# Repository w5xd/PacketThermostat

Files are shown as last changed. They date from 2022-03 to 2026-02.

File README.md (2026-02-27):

<h2>Packet Thermostat Project</h2>

<p>Do you want to access your HVAC over the internet, but not want to open up your home network
some manufacturer's offshore web portal?
Here is an add-on that works on most HVAC systems (<i>i.e.</i> those with 24VAC control 
signals.) You keep
your existing thermostat whether or not it has wifi capability. This packet thermostat exchanges 
radio packets with a gateway to
your Windows or Linux PC. The PC can, in the simplest mode, just monitor the wired
thermostat and report its commands. Or it can modify the commands to, for example, convert a call for
heat pump to a call for the furnace, or it can ignore the wired thermostat and take over 
full control. </p>

It has no hardware buttons. Adjust your conventional thermostat for your comfort when you 
are at home, while instructing this thermostat to its pass-through mode.

The Packet Thermostat must be installed along the wires
between the HVAC and the conventional thermostat. It doesn't matter where as long as there is a way to provide 5VDC to it. 
The packet radio has a range of roughly 500m from the Packet Gateway on a PC.

When you are not at home and need your HVAC settings to change, send a radio packet from the gateway to set this Packet 
Thermostat to one of its controlling modes. 
If your system has one of the simpler one stage or two stage conventional thermostats, the sketch and application
 presented here likely duplicate
its functionality without customization. 

If your HVAC instead has control requirements beyond that implemented here, this project is open source and
free for you to modify. Any HVAC system
with 24V AC control signals and with up to six controls from the thermostat and up to seven 
signals at the furnace can be implemented. (Of what use is that seventh output beyond the six inputs? Maybe 
your HVAC system
has an auxilliary duct booster fan that needs to be activated, say, whenever any of the other six is on.)

This design facilitates integrating the application into a web based home automation system.

There is no GUI for this thermostat in this repository. The repository at 
<a href='http://github.com/w5xd/diysha'>http://github.com/w5xd/diysha</a>
implements a web server that can be used to remotely control this device over the internet.

The device design consists of:
<ul>
<li>A printed circuit board (PCB) which hosts an Arduino, an RFM69 packet radio, 8 total wires (which must include
a power and a common) toward 
the standard wired thermostat, and 14 wires
toward the HVAC. The surplus of wires toward the HVAC unit are to support wired thermometers so this unit
can monitor what is happening right at the furnace. All the parts on the PCB are available at this writing as documented
by this
<a href='https://www.mouser.com/Tools/Project/Share?AccessID=1a8a35c924'>Mouser shared project.</a>.
<li>An enclosure of 3D printable parts that mounts the PCB along with 3 molex connectors. 
This repository has the printable STL files, and also the Solidworks model used to
generate them.
<li>An Arduino sketch.
<li>A command line application  that runs on either Linux or Windows for the purpose of setting
the detailed configuration of the thermostat EEPROM customized to the actual wiring in your HVAC system.
<li><a href='Assembly.md'>Construction details are here</a>.</li>
</ul>

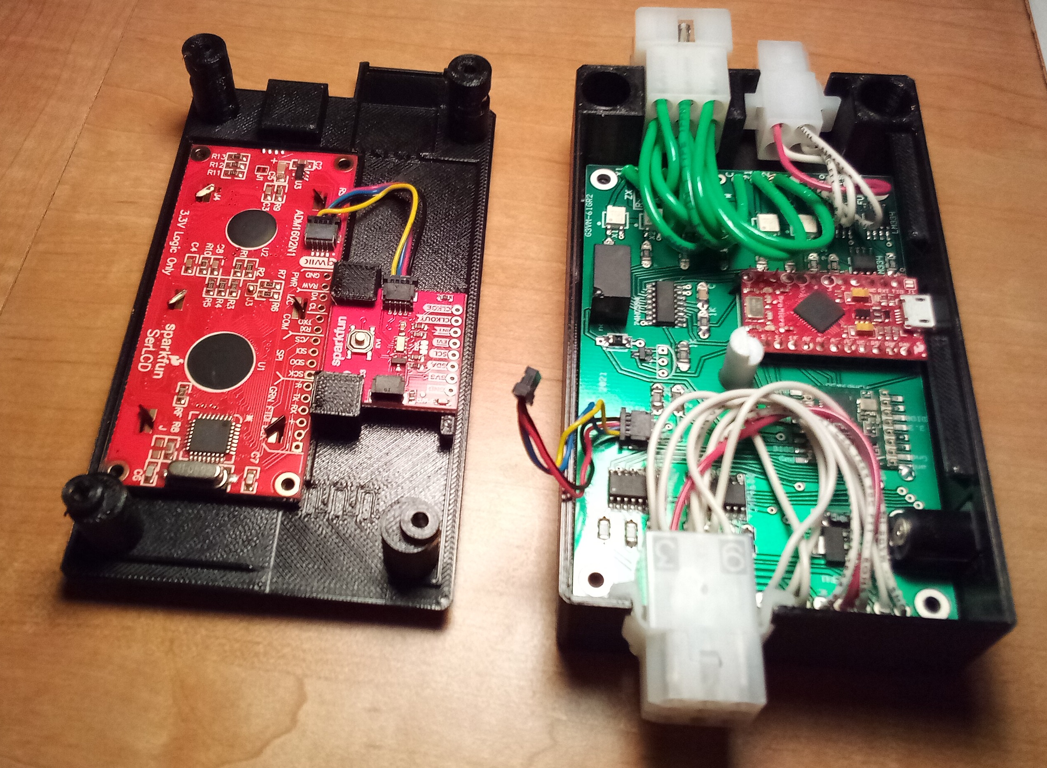
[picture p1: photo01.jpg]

<p style='font-size:11px;font-style:italic'>The PCB version in the photo is older. The CPU in the latest revision
 is a Teensy, and the qwiic connector has opposite orientation, but otherwise the older and new boards are
very similar.</p>

A good summary of the standard
names, colors, and functions of thermostat control wires can be found
<a href='https://www.epatest.com/store/resources/images/misc/how-a-thermostat-operates.pdf'>here</a>.
In terms of that traditional thermostat wiring nomenclature, this PCB supports any installation using 
up to two 24VAC power sources:
<ul>
<li> C (24VAC common)
<li> Either a single R wire, or separate R heat from R cool. (24VAC source or sources traditionally called Rc and Rh.)
</ul>
Signal wires:
<ul>
<li> W, W1 and/or W2 (3 stages of heat)
<li> Y, Y1 and/or Y2 (3 stages of cooling)
<li> O or B (heat pump reversing valve control)
<li> Dehum (dehumidify)
<li> ...any other 24VAC signal that your installation might need up to a total of 6 inputs from the thermostat, and 7 outputs to the HVAC.
</ul>

Of the standard wire names only C, R and W appear on the PCB silkscreen and in the sketch.
For the remaining signals, the convention
in this design is to use the letters X and Z to name them. It is up to the PacketThermostatSettings application to
assign the standard names that appear in your particular HVAC installation to the generic names on this 
thermostat's PCB and sketch.

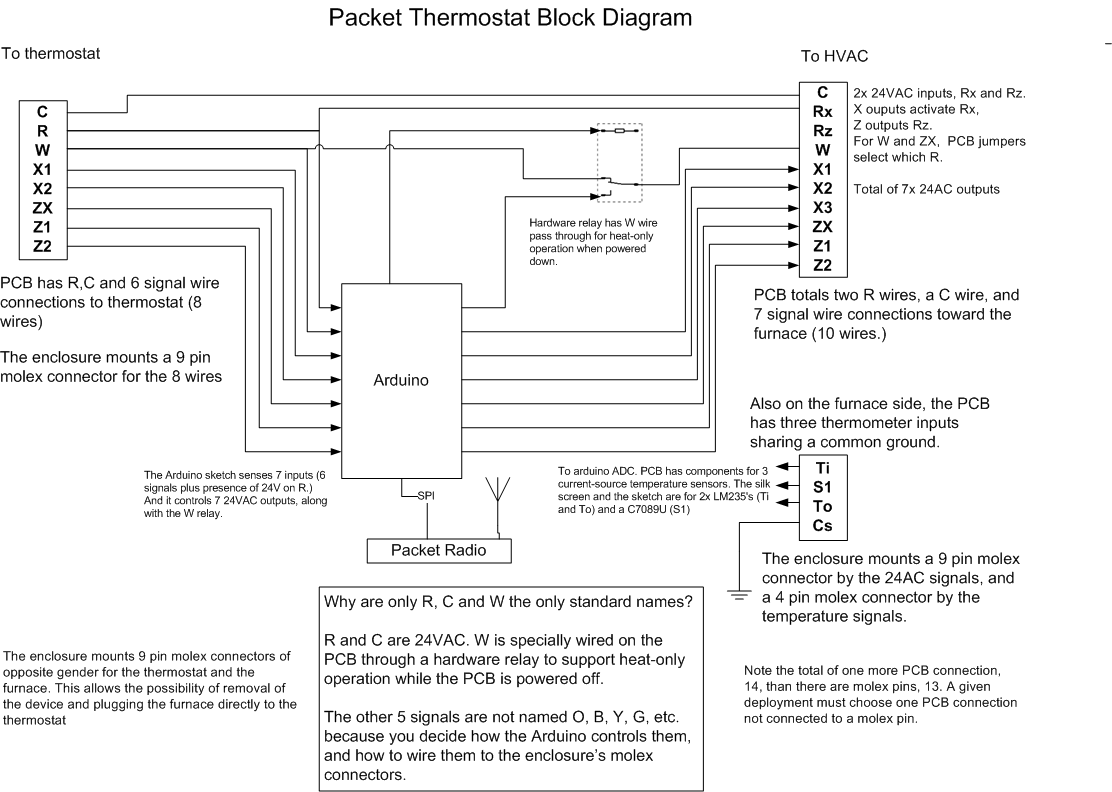
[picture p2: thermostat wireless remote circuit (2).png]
thermostat wireless remote circuit (2).png


The block diagram above shows that the W wire is treated uniquely. It is routed through a hardware relay
that passes the heat signal (W) through when the PCB is powered down. This allows a fail-safe operation so the 
heating function still works
if the Packet Thermostat is not powered, and is why the W wire keeps its standard name. However, 
the PacketThermostatSettings 
application could be modified to reassign even the W wire if your application requires some signal other than W
to be passed through while the 5VDC power is unavailable.

The standard name is also used for the 24VAC supply, R. Like the standard in conventional thermostats,
as many as two are supported by the PCB. But it doesn't use the standard names Rc and Rh. Their names in this 
design are Rx and Rz in order to indicate that the PCB's output signals named
X1 through X3 are powered by Rx, while Z1 and Z2 are powered by Rz. The remaining two outputs, W and ZX are wired
to PCB jumpers to enable installation-specific 24V power from either Rx or Rz on those signals.
If your furnace has only one R wire, the PCB provides a position to jumper the Rx and Rz terminals to each other.

The furnace-facing side of PCB has 4 terminals to support 3 wired thermometer inputs sharing a 
common ground. The sketch
includes the necessary programming to convert the Arduino ADC pin reading for either an 
LM235 solid state thermometer or 
a Honeywell C7089U thermistor.
The silk screen and sketch call out two LM235's and one thermistor, but the only difference 
between the two devices
is one resistor value along with the corresponding programming in the sketch. 
Any combination of those two sensor types totalling 3 can be supported by
substituting the appriorate resistor and modifying the sketch. 

In addition to sending and receiving packets with the Packet Gateway for status updates and changes, the sketch
puts its RFM69 in spy mode such that it receives any Packet Thermometer notifications on its same radio 
frequency and network ID.
Such a Packet Thermometer temperature update (along with its relative humdity update if it sports an HIH6130) are
available to the Packet Thermostat sketch.

The provided sketch software supports being set into any of the following operating types:
<ol>
<li> Pass through.<br/>In this type, it copies each of its 6 inputs to its corresponding output. W to W, X1 to X1, 
X2 to X2, ZX to ZX, Z1 to Z1, and Z2 to Z2. Because it has no corresponding input, X3 will never 
be asserted in Pass through mode.
<li> Map input to output. <br/>In this mode, the thermostat takes its 6 inputs 
(which correspond to 2**6 = 64 combinations)
and updates its 7 outputs to the corresponding value in a 64 byte table. The table is 
configured by the PacketThermostatSettings
application and loaded into the Arduino EEPROM.
<li> Heat. <br/>The thermostat ignores its thermostat inputs. It is instead driven by notifications from one or more 
Packet Thermometers.
This type has several radio-controled settings. One for its target temperature (the turn OFF setting), 
another for its active temperature (its turn ON setting)
along with the required output wire signals for Stage 1, Stage 2, and Stage 3 heating. This thermostat commands Stage 1
on first encountering the activate temperature, then moves to Stage 2 and Stage 3 if the continuous ON time exceeds
the corresponding settings. 
<li> Cool. <br/>The behavior in this type takes the same settings as heat, but takes the opposite 
conditions on the received temperature.
It starts Stage 1 when a temperature
notification exceeds the activate setting, and stops when a notification is below the target. The Cool mode 
also adds a dehumidify setting and a dehumidify output mask. When the humidity is above the setting, the Cool
mode modifies its output.
<li> Auto.<br/>The auto type supports all the Cool type settings and adds a heat target temperature, 
a heat activate temperature, and Stage 1, 2 and 3 timings and output control wire settings.
</ol>

All the above settings are settable by radio packets or by a wired serial port, and all can be commanded to
be stored in the Arduino's EEPROM. The commands are documented in <a href='./Commands.md'>Commands.md</a>. 
Each type also has a five character name, which it will display on the LCD when
commanded into that mode.

The sketch supports a scheduling feature to adjust the Packet Thermostat's target temperature when 
its real time clock reaches a given
hour and minute and day-of-week. It supports a maximum of 16 time points, each with its own target temperature.

The sketch supports a safety shutdown feature that can be configured via its radio or serial port. 
It is independent of the mode settings listed above.
The feature has a trigger temperature for the HVAC input temperature sensor. 
<i>When this trigger temperature is exceeded while the thermostat is in a heating mode, the furnace 
is shut down for a timed interval.</i>
The PacketThermostatSettings application is an easy way to set up
this feature. It sets the required parameters that configure this feature: the trigger 
temperature, the shutdown time,
the thermostat signal combinations that indicate a heat mode, and the thermostat signals to 
turn off to shut down the furnace.

<h2>Power</h2>
The device requires its own 5V power supply. For programming the Arduino, the Teensy version (PCB version 3 and later)
requires both the micro USB connection and the 5V DC power applied. The older PCB with the Pro Micro require
programming using an ISP programmer and with 5V DC not applied.

<h2>Sketch</h2>

PCB version 3 and later has the Teensy 4.0 Arduino, which has far more than enough EEPROM and memory for the sketch.
Earlier versions of the PCB have the Pro Micro. The Pro Micro's flash memory is not big enough to contain this
sketch a boot loader. It is possible to "Upload with Programmer" to program the Pro Micro using (almost) all
its flash and this sketch fits that way. See the comments in the <a href="PacketThermostat/PacketThermostat.ino">sketch</a> for a reference.

Library versions that fit in program Pro Micro memory using Upload with Programmer, and with
modified boards.txt for access to full flash memory:
<code><pre>
Using library RFM69_LowPowerLab at version 1.6.0 
Using library SPI at version 1.0 
Using library Wire at version 1.0 
Using library EEPROM at version 2.0 
Using library SparkFun SerLCD Arduino Library at version 1.0.9 
Using library SparkFun Qwiic RTC RV8803 Arduino Library at version 1.2.10 
Using library WDT_T4 at version 0.1 
Using library SPIFlash 

And in ThermostatCommon.h, these preprocessor directives:
#define USE_SERIAL SERIAL_PORT_SETUP
#define HVAC_AUTO_CLASS 1 // not enough program memory for all features? Turn this off.
</pre></code>

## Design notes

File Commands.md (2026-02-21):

<h2>Commands</h2>

<p>Commands are text sent to the PacketThermostat
by either its USB serial port, or over its packet
radio interface. The commands are described below. The case of the
letters matters and must be as documented. Items in angle brackets like this: &lt;YYYY&gt;
must be present (unless specified otherwise below) and the YYYY is the name of the thing you must enter as is documented
with the command. For this example, YYYY might be a four digit year.</p> 

<p>Many of these command results are saved in the Packet Thermostat's
EEPROM, and many, but not all, such commands are most easily set up 
using the PacketThermostatSettings application published here in this 
repository. PacketThermostatSettings is coded for a particular mapping
of thermostat control wires to the PacketThermostat's input and output pins. 
 You are invited to modify it if your thermostat wiring assignment
 differs.
</p>

<ul>
<li><code>T=&lt;YYYY&gt; &lt;MM&gt; &lt;DD&gt; &lt;HH&gt; &lt;MM&gt; &lt;SS&gt; &lt;DOW&gt;</code><br/>
Sets the real time clock to the year, month, day, hours,
minutes, seconds and day-of-week. Year is four digits, month is 1 through 12,
day is 1 through 31, hours is 0 through 23, minutes and seconds are
0 through 59. DOW is day-of-week and is from 0 through 6 (for
Sunday through Saturday).</li>
<li><code>I</code><br/>
Prints out on the USB serial port what the radio parameters
are set to. Except this command prints nothing if 
the C++ preprocessor setting has eliminated the printout
to preserve program memory.</li>
<li><code>HV &lt;R&gt; &lt;Z2&gt; &lt;Z1&gt; &lt;W&gt; &lt;ZX&gt; &lt;X2&gt; &lt;X1&gt; &lt;X3&gt;</code><br/>
Set wire names to be displayed on the LCD, and
to be reported using the packet radio. At most two characters
are allowed for each of the 8 PCB signals. R, Z2, Z1, W, ZX, X2, X1 and X3
are the names of the physical connectors labeled on the PCB.  They are ordered 
 as above
with the least significant bit for R(bit 0), to the most significant, X3 (bit 
7). This bit order applies in all the signal masks in the remaining
commands below, and for both the inputs to the Packet Thermostat, 
and for its outputs. (The order X2, X1, and X3 is not a typo. That
 is their bit order.) The R wire is not a
signal input used to compute outputs--its the 24VAC supply which means
bit 0 cannot be used in any masks for either input or output. X3 is an
 output, not an input, and R is not an output. The number of input
 signals that can contribute to the output is 6, <code>&lt;Z2&gt;</code>
 through <code>&lt;X1&gt;</code> above, and the number of outputs
 that Packet Thermostat can control is 7: <code>&lt;Z2&gt;</code>
 through <code>&lt;X3&gt;</code> above.
</li>
<li><code>COMPRESSOR=0x&lt;SignalMask&gt; &lt;seconds&gt;</code><br/>
Sets the thermostat's compressor timer lockout bits and timer length.
<code>SignalMask</code> is hexadecimal digits (0 through 9, and A through F). The bit
order as specified in the <code>HV</code> command above. &lt;seconds&gt; is
the length of time the compressor bits are forced to remain
OFF after any of the masked output signals is changed from ON to OFF.</li>
<li><code>DU=F</code> or <code>DU=C</code><br/>
The first sets the LCD temperature units as Farenheit. Otherwise
its Celsius.</li>
<li><code>RH</code><br/>
Forces an update to the LCD, the radio, and
the USB Serial port of the current control wire
inputs and outputs to/from the packet thermostat.</li>
<li><code>HS C &lt;CelsiusX10&gt;</code><br/>
&lt;CelsiusX10&gt; is the heat safety detect
temperature in Celsius times 10. That is, 
<code>HS C 300</code> sets the detection temperature
to 30.0 degrees C. Set to zero to disable
the heat safety detection.</li>
<li><code>HS T &lt;SECONDS&gt;</code><br/>
&lt;SECONDS&gt; is the heat safety timeout. When
the packet thermostat inlet  temperature sensor (wired to Ti on the PCB) exceeds
the threshhold, the furnace heating outputs are held zero
for this long.</li>
<li><code>HS &lt;1-3&gt; &lt;DontCare&gt; &lt;MustMatch&gt; &lt;ToClear&gt;</code><br/>
&lt;1-3&gt; is a digit 1 through 3. Up to three different heat modes can be
detected. (For example: commanding the heat pump on is a different signal configuration
than commanding auxilliary heat, and detecting a heat over temperature for
 the different signal configurations each requires a different <code>HS</code> entry.)
DontCare is a SignalMask (in hex) of the furnace output wires that are not used to detect
the furnace is in a heat mode. MustMatch is the value of the furnace output wire
mask that, once DontCare signals are zeroed, matches the furnace in the heat mode
to be detected.
ToClear is a SignalMask of bits to clear to force the furnace out of the
detected heat mode. </li>
<li><code>SE &lt;ScheduleEntry&gt; &lt;Celsiusx10&gt; &lt;HOUR&gt; &lt;MINUTE&gt; &lt;DAY-OF-WEEK&gt; &lt;AutoOnly&gt;</code><br/>
&lt;ScheduleEntry&gt; is a decimal number in the range of 0 through 15 specifying one of the 16
schedule entries. &lt;Celsiusx10&gt;, &lt;HOUR&gt;, &lt;MINUTE&gt; are decimal numbers.
The temperature is in degrees C times 10 (e.g. 200 means 20.0C). HOUR is the range 0 through 23,
and MINUTE is in the range 0 through 59. DAY-OF-WEEK is a seven bit hexadecimal number in the range of 0 through
7F where each bit specifies a day of the week. Bit 0 is SUNDAY, bit 1 is MONDAY, and so on.
 Unless <code>&lt;AutoOnly&gt;</code> is present and
is the digit <code>1</code>, the Packet Thermostat enforces the schedule
 if is in HEAT or COOL type, setting the target temperature specified by the <code>&lt;Celsiusx10&gt;</code>. 
 If <code>&lt;AutoOnly&gt;</code> is 
 <code>1</code>, the Packet Thermostat sets the heat target temperature if it is in AUTO type.
 If any or all of the values after the ScheduleEntry number are omitted, the corresponding schedule
entry is cleared in the Packet Thermostat's EEPROM.
 </li>
<li><code>HVAC TYPE=&lt;n&gt; COUNT=&lt;m&gt;</code><br/>
&lt;n&gt; is a digit in the range of 0 through 4. The values of n correspond to the types:
<ol type='1' start='0' >
<li>PassThrough<br/> This type has exactly one COUNT, and cannot be changed</li>
<li>MapInputToOutput</li>
<li>HEAT</li>
<li>COOL</li>
<li>AUTO</li>
</ol>
 This command updates the number of MODES in the given TYPE and does so in EEPROM. It <b>destroys</b> the values in
 the Packet Thermostat EEPROM for all TYPES of higher numbers than &lt;n&gt;. All types except PassThrough
may have COUNT=0, which prevents the thermostat from entering that type, even if command to. PassThrough
always has only one MODE, and the only setting it has is its NAME.
</li>
 <li><code>HVAC TYPE=&lt;n&gt; MODE=&lt;m&gt; [BOOT]</code><br/>
 &lt;n&gt; is 0 through 4 as the TYPEs above, and &lt;m&gt; must be less than the number
 specified in COUNT above. This command sets the Packet Thermostat's type and mode of operation. Subsequent
 commands documented below (starting with HVAC) will apply to this particular TYPE and MODE. This
command sets the Packet Thermostat's current operating state and initializes its
settings from EEPROM. If the command is followed by the word "BOOT" it also
sets the EEPROM state to restore this TYPE and MODE should the
thermostat power down and back up.</li>
 <li><code>HVAC COMMIT</code><br/>
 The HVAC_SETTINGS and HVAC commands (below) are not written to EEPROM until this COMMIT command. This means, for example, that
 if "HVAC_SETTINGS 200" has been used to set the current target temperature to 20C (which is 68F) and for
 any reason the Packet Thermostat loses power, the HVAC_SETTINGS are restored to what they were at 
 the previous HVAC COMMIT (not necessarily the previous HVAC_SETTINGS)</li>
<li><code>HVAC FAN=ON</code> or <code>HVAC FAN=OFF</code><br/>
 This command only has effect when the Packet Thermostat is in HEAT, COOL or AUTO type.<br/>
Sets or clears the ventilation fan to continuous ON mode.</li>
<li><code>HVAC NAME=&lt;name&gt;</code>
<br/>The name displayed for the current TYPE and MODE in the LCD. Five characters maximum.</li>
<li><code>HVAC_SETTINGS &lt;target temperature Cx10&gt; &lt;activate temperature Cx10&gt; &lt;sensor id mask&gt; &lt;Stage 1 Mask&gt; &lt;Stage 2 Mask&gt; &lt;Stage 3 Mask&gt; &lt;Fan Mask&gt; &lt;Seconds to Stage 2&gt; &lt;seconds to Stage 3&gt;</code><pre>
For EXAMPLE, to set the thermostat COOL type with typical mapping of PCB to thermostat wires:
                 206     decimal. target is 69F (20.6C)  
                 211     decimal. activate at 70F (21.1), 
                 300     hex. use sensors 8 and 9
                  10     hex. The Fan is the G wire, mapped to Z1
                  04     hex. Keep the O output, mapped to X1, always ON
                  08 08 08     hex. Stages 1, 2 and 3 are all Y output, mapped to X2
                   1  1        decimal. Seconds to stages 2 and 3 are unimportant, 1 second each
     HVAC_SETTINGS 206 211 300 10 04 08 08 08 1 1
</pre> Leading zeros as shown above are allowed but are not required.
 Any or all of the values after the &lt;target temperature Cx10&gt; may be omitted. If the 
&lt;activate temperature Cx10&gt; is omitted, it is calculated as 0.6C above/below the target,
as is appropriate for the given type. All settings in the command after the activate temperature are
retained unchanged from their setting at the time of this command. <br/>
This same command is used for HEAT type as well, but in HEAT you must set the activate temperature
lower than the target temperature (or omit it and it will be set 0.6C below the target.)<br/>
The Seconds-to-stage settings are timed from when stage 1 was started (not from
when any previous stage was started.)<br/>
 This command only has effect when the Packet Thermostat is in HEAT, COOL or AUTO type.</li>
<li><code>HUM_SETTINGS &lt;HumdityX10&gt; &lt;MaskON&gt; &lt;MaskOFF&gt;</code><br/>
This command only has effect if TYPE=2 (COOL) or TYPE=3 (AUTO)<br/>
&lt;HumdityX10&gt; is percent humidty times 10 in decimal (e.g. 400 is 40% humidity.)
The two masks are hexadecimal. <code>&lt;MaskON&gt;</code> specifies the output bits to
turn on when the humidity exceeds the setting and <code>&lt;MaskOFF&gt;</code> specifies
the bits to turn off, also on high humidity. When the humidity input
is below the setting, the appropriate <code>Stage n Mask</code> specifies
the output.</li>
<li><code>AUTO_SETTINGS &lt;target heat Cx10&gt; &lt;activate heat Cx10&gt; &lt;Stage 1 Mask&gt; &lt;Stage 2 Mask&gt; &lt;Stage 3 Mask&gt;</code><br/>
This command only has effect if TYPE=3 (AUTO)<br/>
AUTO mode uses the <code>HVAC_SETTINGS</code> for cooling, and for heating, it uses these settings. The seconds-in-stage for
heating in AUTO are the same for heating as for cooling as specified in  <code>HVAC_SETTINGS</code>. 
If only the target heat temperature is specified, the activate temperature is set to 0.6C lower.</li>
<li><code>HVACMAP=0x&lt;addr&gt; &lt;v1&gt; &lt;v2&gt; ... &lt;v8&gt;</code><br/>
This command only has effect if TYPE=1, MapInputToOutput<br/>
The MapInputToOutput has 64 one-byte entries in its map. Each entry corresponds
to one of the 64 possible combintations of the 6 inputs being either on (represented
 by a one) or off (represented by zero.) The <code>&lt;addr&gt;</code> is hex and
 sets the position in the map of the next argument,  <code>&lt;v1&gt;</code>. Up
 to 8 mask entries may be specified with <code>&lt;v2&gt;</code> and so on
each applied to the next higher <code>&lt;addr&gt</code>. To fully specify the map 
requires issuing this command at least 8 times starting with, for example, <code>HVACMAP=0x0 0 1 2 3 4 5 6 7</code>
up to the eighth command which might look like <code>HVACMAP=0x38 38 39 3A 3B 3C 3D 3E 3F </code>. This example
shows the first and last commands of eight that would set up a map where the Packet Thermostat output wires
are set to match its input wires (which is exactly what <code>HVAC TYPE=0 MODE=0</code> does.) All
the values &lt;addr&gt; and &lt;v1&gt; through &lt;v8&gt; are hexadecimal.
This command is the only exception to the rule that input and output masks are
 computed as bit masks with the R signal as bit zero. The output values (<code>&lt;v1&gt;</code> and so on) in this
command <i>are</i> in that coding but the &lt;addr&gt; values are <i>not</i>. This is because the R signal is ignored when 
 the Packet Thermostat calculates
the map entry. Instead, for the purpose of specifying <code>&lt;addr&gt;</code>, Z2 is bit zero. 
Therefore, the 64 valid values for  &lt;addr&gt; start at zero for the
case of the 6 inputs Z2 through X1 off, the value 0x1 is for only Z2 on, up through
0x3F for all inputs Z2 through X2 on.
</li>
</ul>

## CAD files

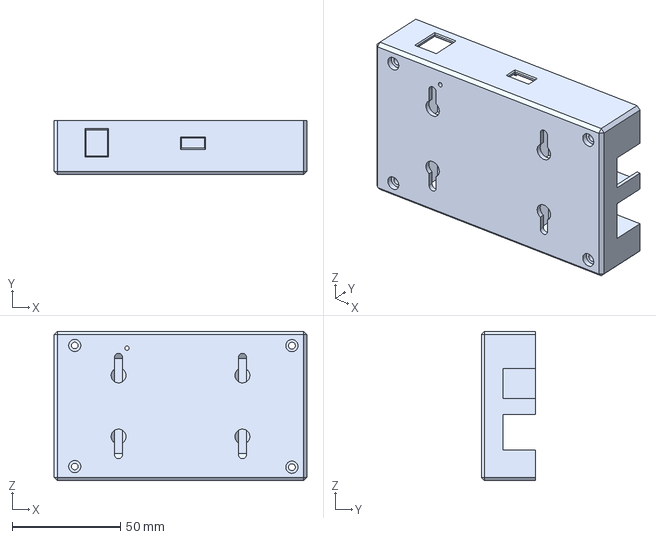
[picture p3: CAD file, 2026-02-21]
CAD/EnclosureBase.stp
116.7 x 25.1 x 68.8 mm

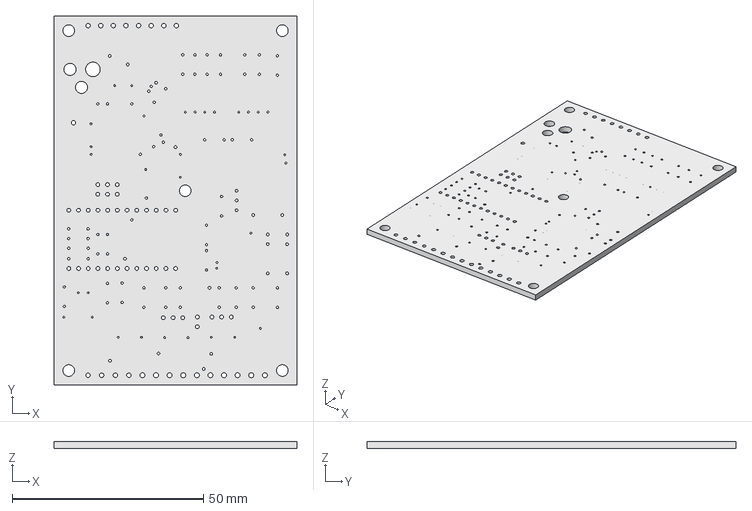
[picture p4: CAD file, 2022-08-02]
PCB/PCB.step
63.5 x 96.5 x 1.78 mm

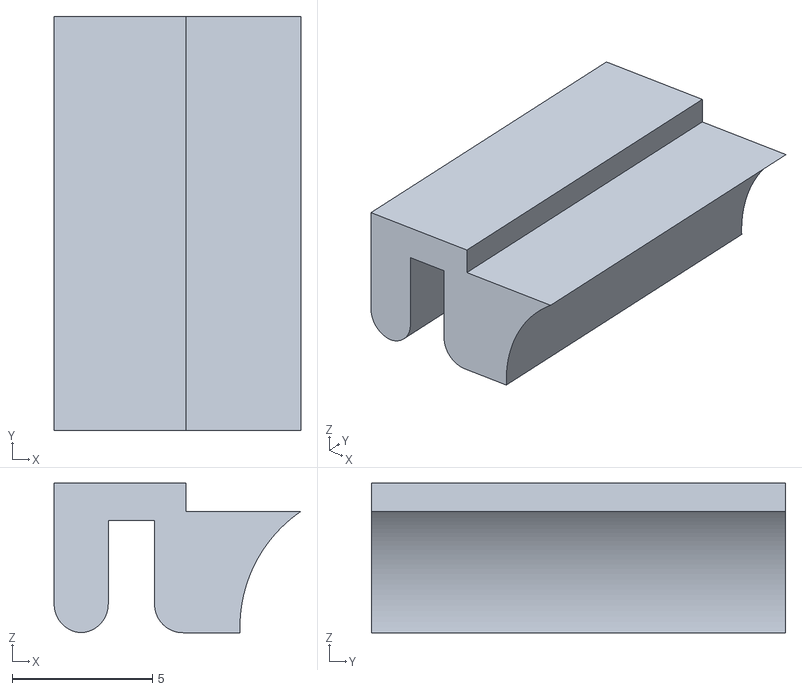
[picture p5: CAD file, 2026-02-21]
STL/Molex9InsertB.stl
8.80 x 14.8 x 5.33

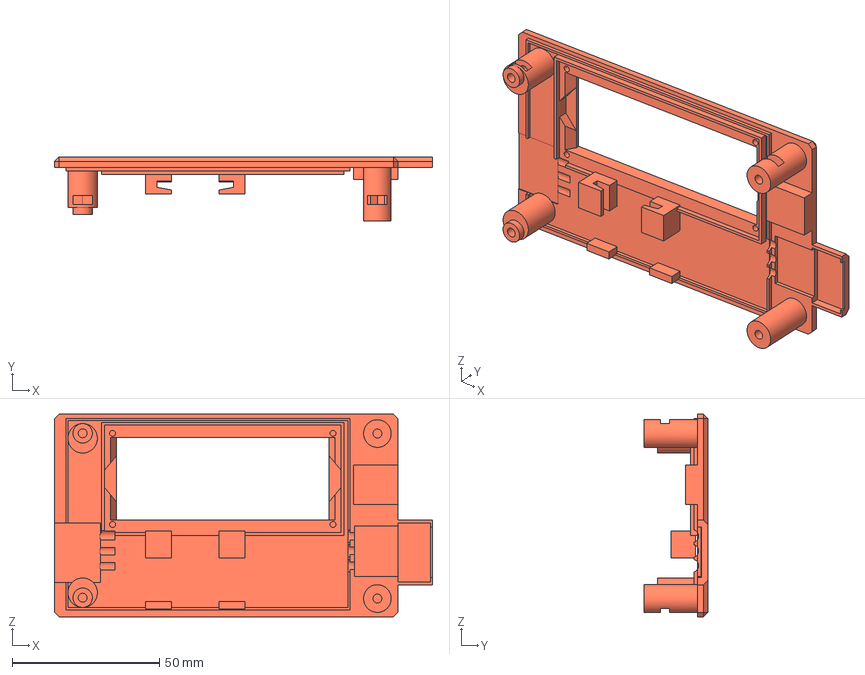
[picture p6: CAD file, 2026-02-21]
CAD/EnclosureTop.stp
128.5 x 21.9 x 68.8 mm

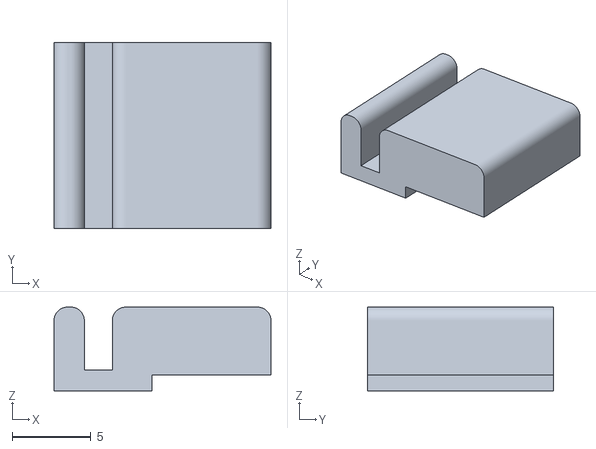
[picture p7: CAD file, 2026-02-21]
STL/Molex9Insert.stl
13.8 x 11.9 x 5.33

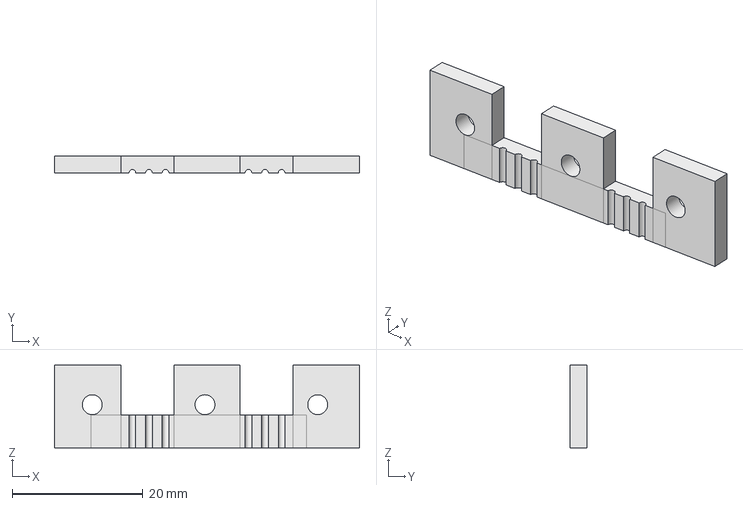
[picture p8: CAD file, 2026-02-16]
CAD/ProMicroISP.FCStd
46.7 x 2.54 x 12.7 mm

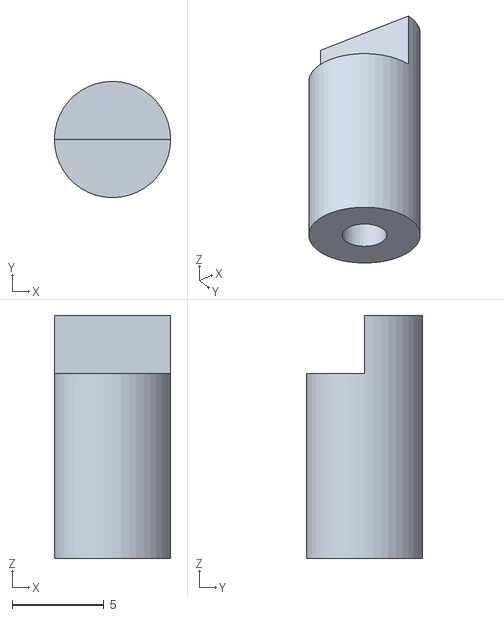
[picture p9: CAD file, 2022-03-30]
STL/LCD pcb brace.STL
6.35 x 6.35 x 13.3

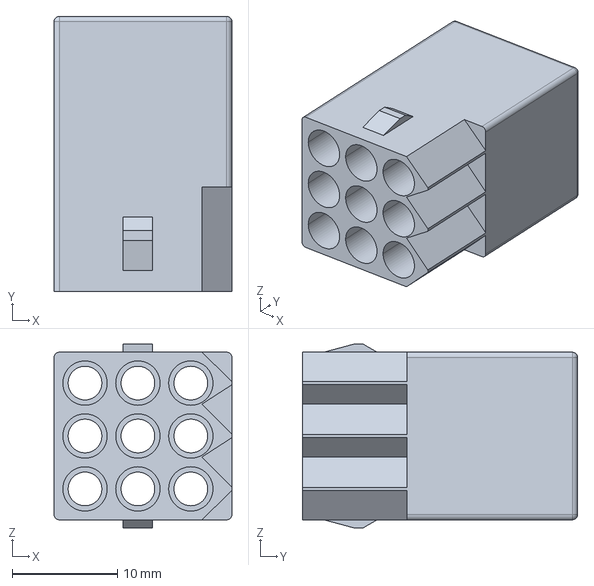
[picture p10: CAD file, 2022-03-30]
CAD/003091094.stp
16.9 x 26.2 x 17.4 mm

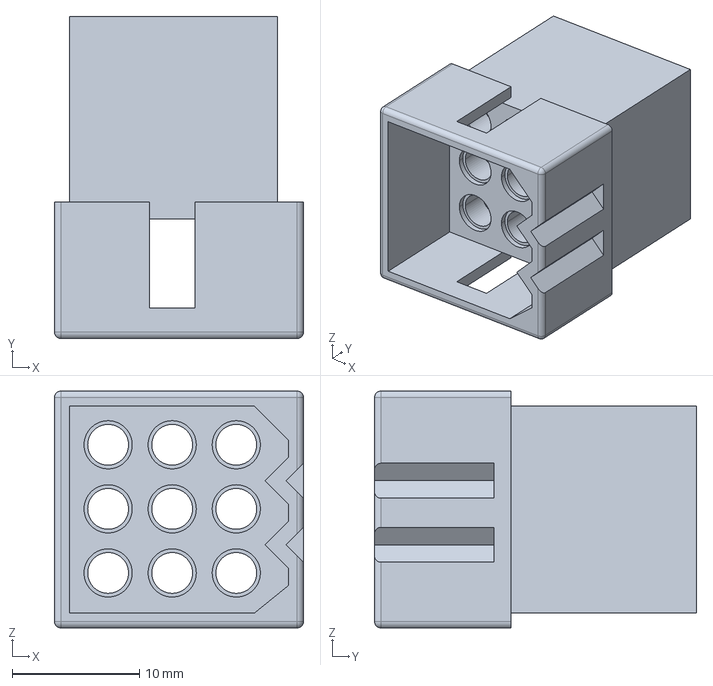
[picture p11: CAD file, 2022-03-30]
CAD/003092092.stp
19.6 x 25.3 x 18.6 mm

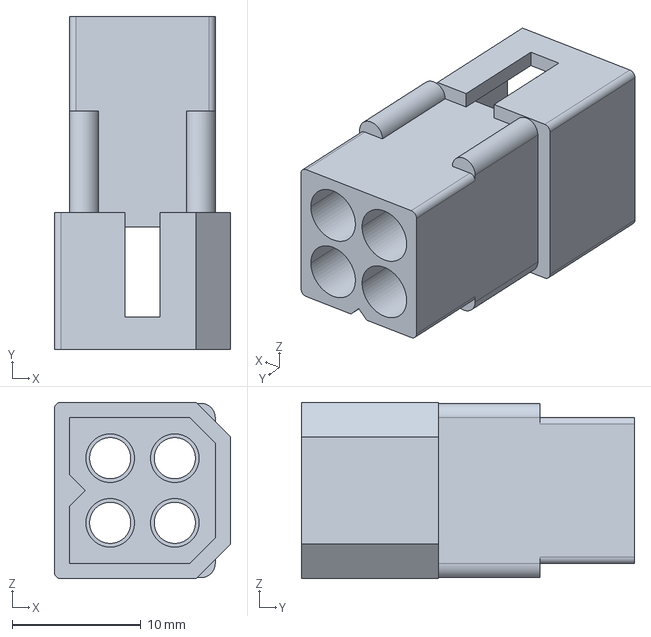
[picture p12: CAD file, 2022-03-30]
CAD/003092049.stp
13.7 x 25.9 x 13.7 mm

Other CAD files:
STL/EnclosureBase.STL
STL/EnclosureTop.STL

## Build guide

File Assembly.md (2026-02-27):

<h2>Printed Circuit Board</h2>
The gerber files for REV04 PCB fabrication are <a href='PCB/REV04-Gerbers.zip'>here</a>. 
While there are some through-hole patterns on the PCB,
many of the parts are available only SMD. A <a href='https://www.whizoo.com/controleo3'>Reflow Oven</a> makes PCB assembly
faster and easier. Or if your hand is steady enough for 50 thou IC pin spacing, you can hand solder.
I had bad results reflow soldering with the RFM69 in place. Solder paste spreads under the 
module and shorts its vias. Its easier to hand solder it.
All parts mount on the PCB top. <br/><br/>
<p style='margin-top:8px'>The enclosure is 3D printable on common 3D printers. The printable STL files 
are <a href="STL">here</a>. If instead you want to design a different enclosure, then you are welcome to start with the
CAD models <a href="CAD">here</a>.</p>
<p>I used PETG filament. It prints in three parts: the top, the bottom and a 1/4" diameter bracing cylinder.
Where does that little cylinder go? Use a #4 machine screw x 1/8" inserted 
through the bottom of the PCB in the hole in the middle of the board. The cylinder 
is permanently left in place (only <i>after</i> you have reflow soldered, of course.)
Orient it so its rounded edge faces the PCB board edge in the direction of the qwiic connector. Its purpose is 
to keep both the LCD and the PCB from
falling into the center of the enclosure by pressing them against the top and bottom, respectively.
</p>

The enclosure <b>top</b> has nut slots for 4 nuts, one each on the sides of the legs. Four #4 machine screws, 5/8" long, 
enter through the enclosure bottom and hold the entire assembly together.
(On the enclosure <b>bottom</b> 
there are two more slots if you happen to find them, but you may safely ignore 
these nut slots on the enclosure bottom. Those 4 screws through the entire assembly hold the PCB securely in place.)

<p><a href='https://www.mouser.com/Tools/Project/Share?AccessID=1a8a35c924'>Here</a> is a Mouser shared project with all the parts except the PCB, enclosure, and hookup wire.

<ol>
<li> <a href='https://www.sparkfun.com/teensy-4-0.html'>Teensy 4.0</a>. All power is solely from the 5V 
power jack, which requires: <i><b>before installing</b></i>, cut the Teensy's back side VIN/VUSB jumper.
</li>
<li> <a href='https://www.sparkfun.com/products/16281'>SparkFun Real Time clock module, RV-8803</a> </li>
<li> <a href='https://www.sparkfun.com/products/13909'>Sparkfun RFM69HCW packet radio module.</a></li>
<li> <a href='https://www.sparkfun.com/products/14417'>Sparkfun Qwiic SMD connector</a></li>
<li> <a href='https://www.sparkfun.com/products/16396'>Sparkfun 16x2 SerLCD -RGB - Qwiic</a></li>
<li> <a href='https://www.mouser.com/new/omron-electronics/g3vm-vr-mosfet-relays/'>G3VM-61GR2 Omron
Solid State Relay<a>. (Quantity: 7)</li>
<li> <a href='https://www.mouser.com/datasheet/3/190/1/sy.pdf'>SPDT relay</a></li>
<li> <a href='https://www.vishay.com/docs/83512/tcmt1600.pdf'>Quad 
Optoisolator AC input, 4mm 16-SOP</a>. (Quantity: 2)</li>
<li> <a href='https://www.st.com/resource/en/datasheet/lm234.pdf'>LM334 Current Source, 8-SOIC</a>, 4mm width. (Quantity: 3)
<br/>Pin 1 is on the beveled side of the LM334</li>
<li> <a href='https://www.mouser.com/datasheet/3/175/1/AZ1117I.pdf'>3.3V regulator, SOT223</a></li>
<li> <a href='https://www.mouser.com/datasheet/3/101/1/MMBT100-D.PDF'>2n3904 (or equivalent) in SOT-23</a></li>
<li> <a href='https://www.ti.com/lit/ds/symlink/sn74hc594.pdf'>74hc594 shift register in 4mm width 16-SOIC </a></li>
<li> All resistors and capacitors on the PCB have dual SMD pads size 1206. Except the SMD for the 10uF polarized is 2312</li>
<li> Use a 5VDC wall wart. Do not use anything higher than 6V!
</ol>
All of the Sparkfun products listed above are also in Mouser's catalog. 

|Quan|Item|Value|Form|
|:-|:-|:-|:-|
|1|C1|10µF|EIA 2312|
|3|C2, C3, C4|.022µF|Chip EIA 1206 |
|2|C5, C6|.01µF|Chip EIA 1206 |
|3|CS2, CS3, CS4|LM334|SO8 208 mil 8S2|
|1|D1|1N4148|EIA 1206 or  DO-35 (0.3 in hole spacing)|
|1|J15|2.1 mm barrel jack PJ-202A|for power plug|
|1|Q13|2N3904 or similar|SOT-23 or TO-92|
|2|R1, R2|1K|EIA 1206|
|3|R5, R6, R52|2.2K|EIA 1206|
|7|R31, R32, R33, R34, R35, R36, R37|18K|EIA 1206|
|7|R41, R42, R43, R44, R45, R46, R47|180|EIA 1206|
|2|R50, R51|68|EIA 1206|
|3|R53, R54, R55|10K|EIA 1206|
|1|U2|74HC594|SOIC 16|
|2|U3, U4|TCMT4600|SOP-16|
|1|U5|AZ1117|SOT-223|
|7|U11, U12, U13, U14, U15, U16, U17|G3VM-61GR2|SOP-4|

Mechanical parts:
<ol>
<li> <a href='https://www.molex.com/en-us/products/part-detail-pdf/03091094?display=pdf'>9 pin Molex 03091094 RECPT free hanging</a>. (Quantity: 2)</li>
<li> <a href='https://www.molex.com/en-us/products/part-detail-pdf/03092092?display=pdf'>9 pin Molex 03092092 PLUG free hanging</a>. (Quantity: 2)</li>
<li> <a href='https://www.molex.com/en-us/products/part-detail-pdf/469990653?display=pdf'>4 pin Molex 469990653 RECPT panel mount</a></li>
<li> <a href='https://www.molex.com/en-us/products/part-detail-pdf/03092049?display=pdf'>4 pin Molex 03092049 PLUG</a></li>
<li> <a href='https://www.molex.com/en-us/products/part-detail-pdf/02092118?display=pdf'>Molex 02-09-2118 PIN</a>. (Quantity: 22)</li>
<li> <a href='https://www.molex.com/en-us/products/part-detail-pdf/02091119?display=pdf'>Molex 02-09-1119 SOCKET</a>. (Quantity: 22)</li>
<li> <a href='https://www.digikey.com/en/products/detail/molex/0003091091/26302'> No longer available. 9 pin Molex RECPT panel mount</a>. 
Modify the free hanging 9 pin RECPT above: 3D print the Molex9Insert's, and use Gorilla glue double-sided tape.</li>
<li> <a href='https://www.mouser.com/datasheet/3/6118/1/pj_202a.pdf'> PJ-202A 2MMx5.5MM kinked pin power jack</a></li>
<li> <a href='https://www.mouser.com/datasheet/3/85/1/htsw_th.pdf'>Samtec TSW-150-07-T-S 0.100 inch Connection headers</a>. (Quantity: 3)<br/>
Use this specified header soldered both sides and without a socket to be sure the micro USB on the CPU lines up with its hole in the enclosure</li>
<li> <a href='https://www.sparkfun.com/products/17260'>50mm Qwiic cable</a>. (Quantity: 2)</li>
</ol>
The Molex quantities listed include (exactly enough) parts to populate the enclosure <i>and</i> one free hanging mating connector.

<p style='margin-top:9px'>You have to decide at assembly time which PCB otuput/input should be wired to which 
Molex pin number. Here are some recommendations:</p>
<ul>
<li> Use the same pinout on the two 9 pin molex housings, and put pins in one and sockets in the other. The result is that 
you can
unplug the packet thermostat and plug the two hanging connectors to each other and the furnace will operate without it.
Maybe your HVAC service person would be more comfortable working on a unit without a mysterious box on its 
control cable?</li>
<li>AWG 18 wire is recommended for the furnace-facing 9 pin molex. </li>
<li>AWG 18 wire is also recommended for the thermostat side for the W, R and C wires because they carry the
full current demand of the furnace/wall-thermostat connection.</li>
<li>A smaller gauge, e.g. AWG 24, is fine for the remainder of the thermostat-facing molex, and for the wires to the thermometers as all of these carry much smaller current.</li>
<li>Along the furnace facing side of the board, the number of holes in the PCB (14) is one more than the 
number of pins in the specified
Molex connectors (13). If you're still looking for another wire into the enclosure, a last resort might be the
opposite side of the PCB. It has the reverse
situation: one more molex pin (9) than holes in the PCB (8).
</ul>
Part orientations
<ul>
<li>Only one orientation of the RTC module fits the enclosure:
<ul>
<li>Its qwiic connectors face away from the enclosure top
<li>The lithium cell faces toward the enclosure top, and is towards the LCD display.
</ul></li>
<li> The RTC module has two qwiic connectors. Electrically, it does not matter which goes to the 
LCD and PCB, but you'll discover the 50mm length cables only fit one way.
<li>The LCD display recommended orientation is that its lettering is upright when 
the LCD window in the enclosure is LOWER. It can be oriented the other way,
but there are two disadvantages to the other orientation.
<ul>
<li>The specified 50mm qwiic cable is too short
<li> The micro-USB and 5VD power holes are on the box top where gravity pulls dust into the box.
</ul></li>
</ul>

There are 3 jumper positions. Two of them <b>require</b> you install a jumper: the outputs ZX and W
each may be powered from either Rx or Rz, but no jumper means no power. To know which
R in the thermostat to connect to which R in the furnace, you need to 
<a href='https://www.epatest.com/store/resources/images/misc/how-a-thermostat-operates.pdf'>know a little about how your 
furnace is wired</a>. Its easy if your furnace has only a single 24V AC power wire ("single transformer" in the
link above), usually called R, in which
case jumper the PCB position for single source Rx and Rz (the jumper position on the PCB between the 
boxes for ZX and W) and also install a jumper in the ZX and W boxes, and, for a single source,
it makes no difference which jumper position you choose.

To repeat: in both the ZX and W boxes, a jumper must be placed from the center hole to either the one above (Rx)
or the one below (Rz).

If your furnace has split 24V AC power, then you have to know which thermostat wires need to be powered
from which R wire (Rx or Rz) and you have to choose the PacketThermostatSettings to match,
and you need to take care in which position you jumper the ZX and the W box, and you must <b>not</b> install the Rx/Rz jumper.

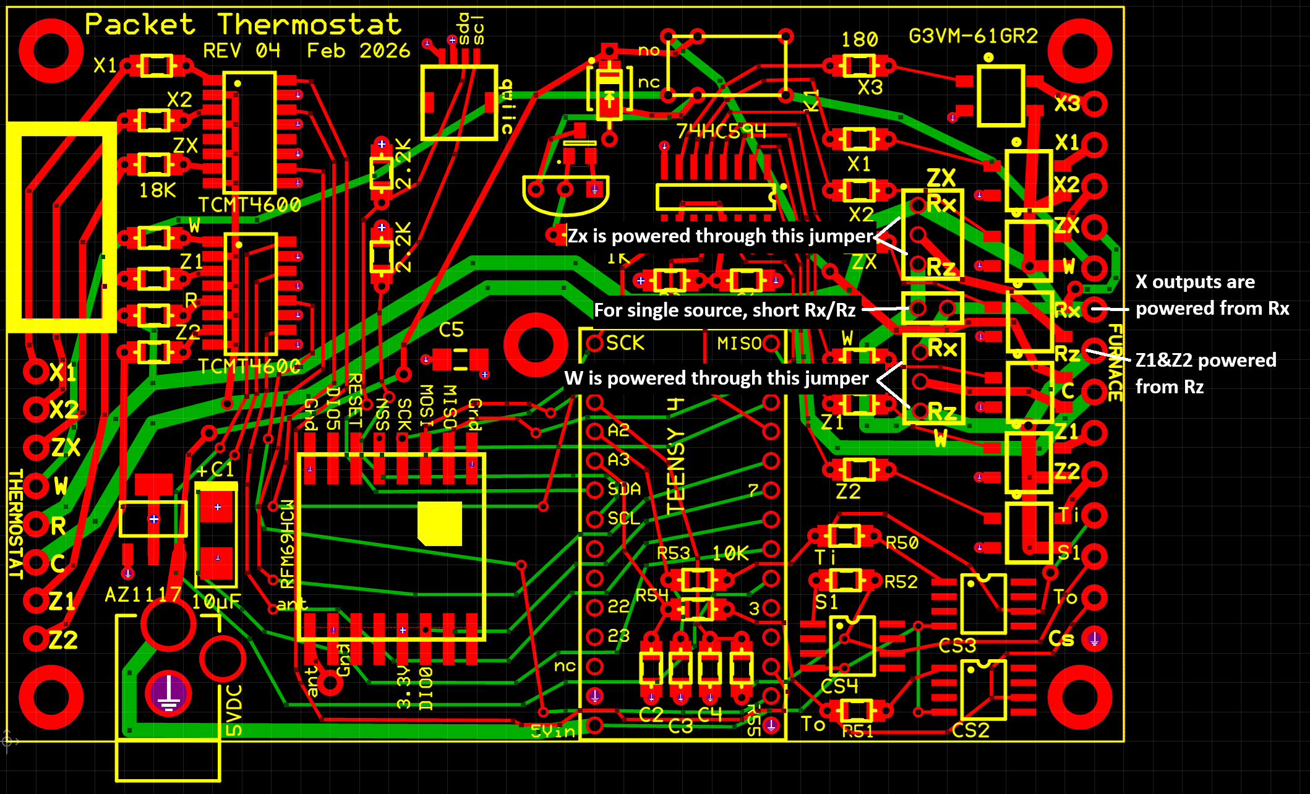
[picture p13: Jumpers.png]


Firmware and initial test
<ol>
<li>Load the sketch on the Arduino using the Arduino IDE (or the software tool of your choice).
<li>The packet radio won't function until you program its Network ID, Node ID, and Frequency Band into its 
EEPROM. And if you're running your gateway
encrypted, you have to specify the key. (By the way, the symptom if the encryption keys on this thermostat and
the gateway do not match, is the packets are delivered anyway, but they are gibberish.)
<li>On an out-of-the-box Arduino, the EEPROM comes will all bits set, which corresponds to no types 
nor modes other than 
Pass through per the below instructions. The commands here initialize the thermostat
to pass-through mode. Use the Arduion IDE "Serial Monitor" function with 9600 baud set. The 
Arduino sketch, if properly installed, will response "ready>" after each command. If not...check the hardware 
and/or upload the sketch again.
<ul>
<li> HV R d G W Y2 Y O
<li> HVAC TYPE=1 COUNT=0
<li> HVAC TYPE=2 COUNT=0
<li> HVAC TYPE=3 COUNT=0
<li> HVAC TYPE=4 COUNT=0
<li> HVAC TYPE=0 MODE=0
<li> HVAC NAME=PasT
<li> HVAC COMMIT
</ul> On the penultimate command, the LCD should display the name <code>PasT</code></li>
<li> I strongly recommend you first test <i>only</i> the fan function (Green control wire). Most thermostats have 
a Fan On button. Try it. If anything is wrong, you have only one 
signal to debug. Its up to you to get the wire assignments right. Get them wrong on the furnace side of this
device and the device LCD displays one thing, but the furnace gets something else. 
<li> Test with the device wired between the conventional thermostat and the furnace. If the packet radio EEPROM setup is done,
you'll get messages at your gateway when the control wires change, but regardless of the radio, the thermostat should
pass through all incoming 24VAC signals from the thermostat to the furnace while displaying its output wire 
states on its LCD.
</ol>

The 3D printed adapters that make the 9 pin "free hanging" into a no-longer-manufactured "panel mount" are fastened to the free hanging molex receptacle using cut-to-fit squares of Gorilla tape like in the photos below. Cut the tape oversize, stick it to the 
insert, then use a sharp blade to trim the tape to the size of the insert. Mind the orientation. The free hanging Molex is flat
on all four sides, but there is only one orientation that matches what is installed on the furnace side.
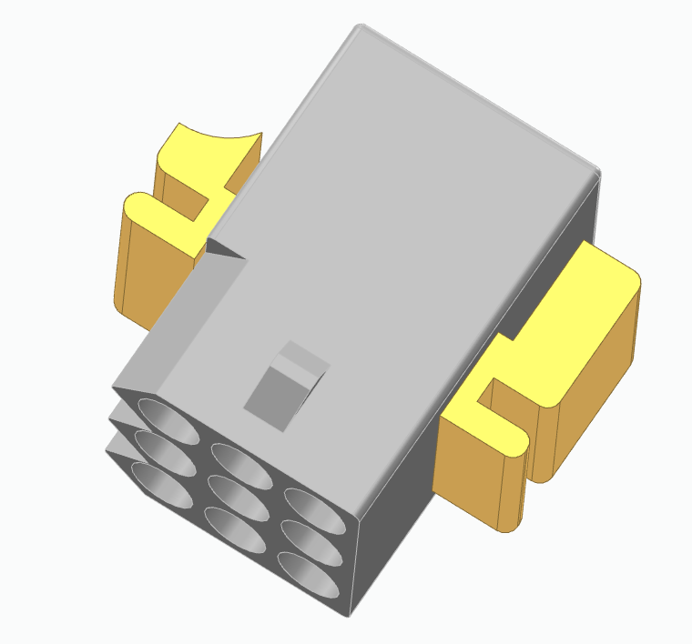
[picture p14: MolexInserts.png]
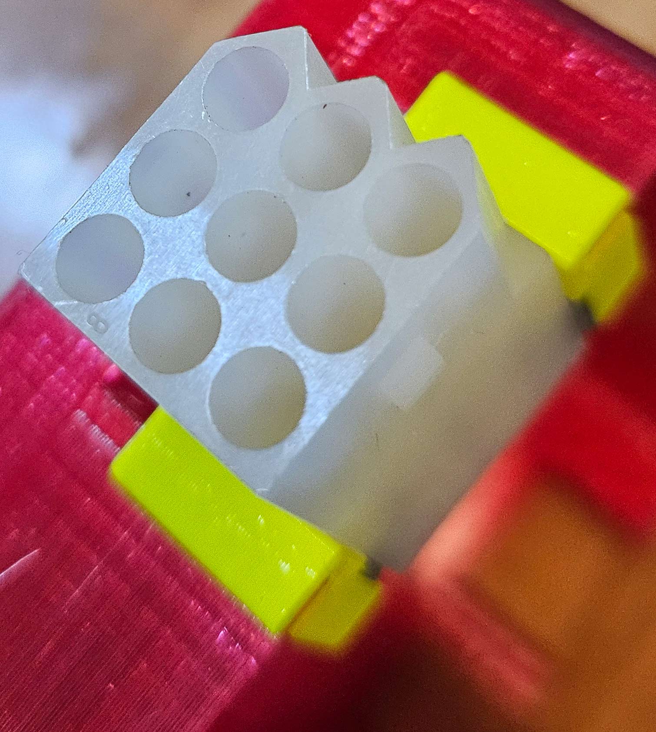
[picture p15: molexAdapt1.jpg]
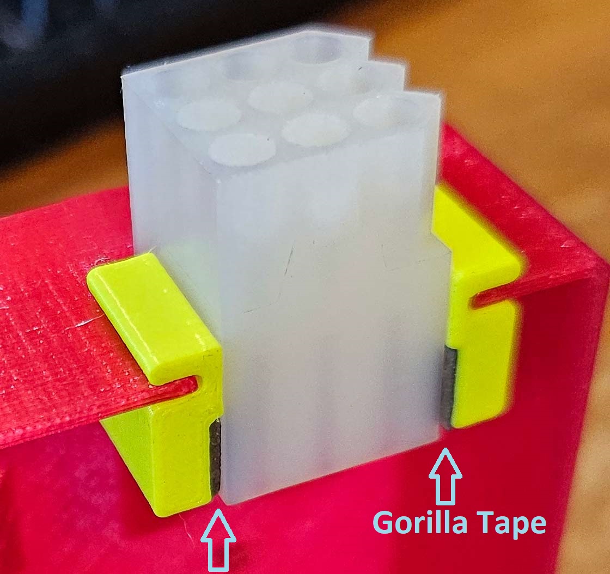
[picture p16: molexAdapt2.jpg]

The adapters should be flush with the pin 3/9 edge of the molex, not the pin 1 edge, in order to clear the wires coming off the PCB (not pictured.) When the inserts are
first installed, it may seem they slide too easily. But after the enclosure covers are 
fastened to each other, they apply pressure to the tape that should be enough to resist the forces required to connect and disconnect the mating 9 pin Molex.

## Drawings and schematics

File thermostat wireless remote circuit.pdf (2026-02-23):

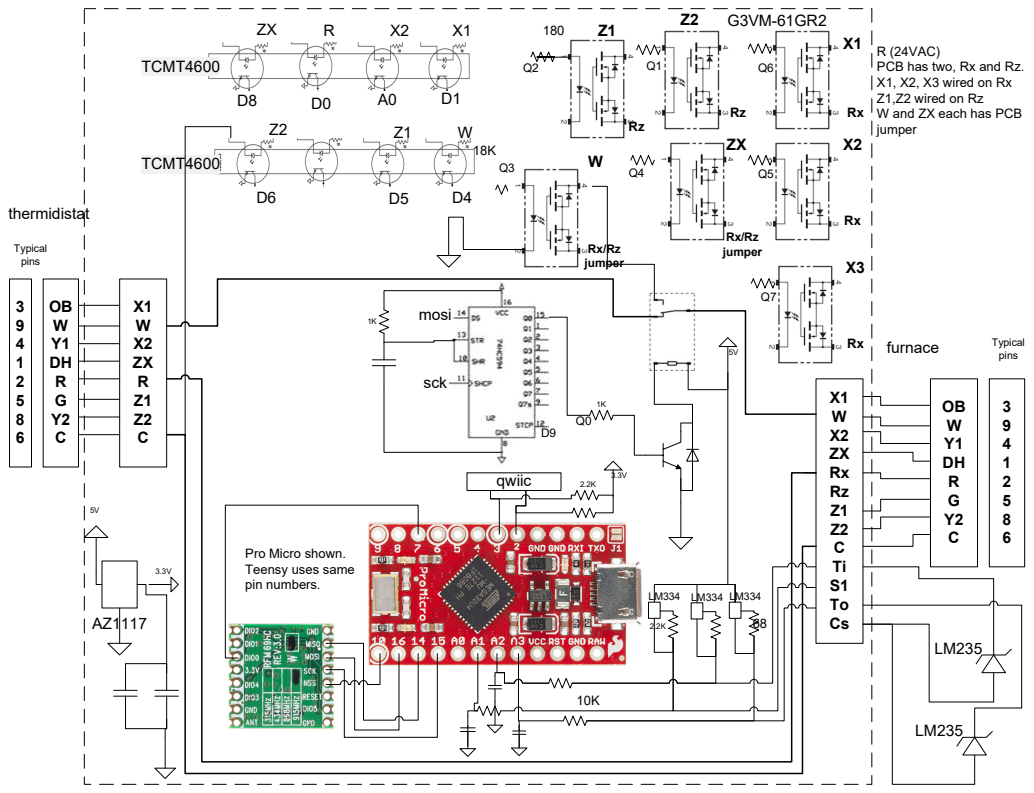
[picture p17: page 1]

R (24VAC)
PCB has two, Rx and Rz.
X1, X2, X3 wired on Rx
Z1,Z2 wired on Rz
W and ZX each has PCB
jumper

## Packet Thermostat Block Diagram

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
To thermostat | To HVAC

PCB has R,C and 6 signal wire connections to thermostat (8 wires)

The enclosure mounts a 9 pin molex connector for the 8 wires

PCB totals two R wires, a C wire, and

### 7 signal wire connections toward the

furnace (10 wires.)

Also on the furnace side, the PCB has three thermometer inputs sharing a common ground.

The enclosure mounts a 9 pin molex connector by the 24AC signals, and a 4 pin molex connector by the temperature signals.

Note the total of one more PCB connection, 14, than there are molex pins, 13. A given deployment must choose one PCB connection not connected to a molex pin.

The enclosure mounts 9 pin molex connectors of opposite gender for the thermostat and the furnace. This allows the possibility of removal of the device and plugging the furnace directly to the thermostat

Arduino

Packet Radio

SPI

Hardware relay has W wire
pass through for heat-only operation when powered down.

2x 24VAC inputs, Rx and Rz. X ouputs activate Rx,
Z outputs Rz.
For W and ZX, PCB jumpers
select which R.

Total of 7x 24AC outputs

The Arduino sketch senses 7 inputs (6 signals plus presence of 24V on R.) And it controls 7 24VAC outputs, along with the W relay.

To arduino ADC. PCB has components for 3 current-source temperature sensors. The silk screen and the sketch are for 2x LM235's (Ti and To) and a C7089U (S1)

Why are only R, C and W the only standard names?

R and C are 24VAC. W is specially wired on the PCB through a hardware relay to support heat-only operation while the PCB is powered off.

The other 5 signals are not named O, B, Y, G, etc. because you decide how the Arduino controls them, and how to wire them to the enclosure’s molex connectors.

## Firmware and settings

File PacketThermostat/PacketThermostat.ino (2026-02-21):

/* (c) 2026 by Wayne E. Wright, Round Rock, Texas, USA

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
THE SOFTWARE IS PROVIDED "AS IS", WITHOUT WARRANTY OF ANY KIND, EXPRESS OR
IMPLIED, INCLUDING BUT NOT LIMITED TO THE WARRANTIES OF MERCHANTABILITY,
FITNESS FOR A PARTICULAR PURPOSE AND NONINFRINGEMENT. IN NO EVENT SHALL THE
AUTHORS OR COPYRIGHT HOLDERS BE LIABLE FOR ANY CLAIM, DAMAGES OR OTHER
LIABILITY, WHETHER IN AN ACTION OF CONTRACT, TORT OR OTHERWISE, ARISING FROM,
OUT OF OR IN CONNECTION WITH THE SOFTWARE OR THE USE OR OTHER DEALINGS IN
THE SOFTWARE. */

/*
** 
** Arduino Sketch for the packet thermostat using its associated printed circuit board.
**
** The packet thermostat is designed to intervene between an existing wall mounted,
** user accessible thermostat when connected between it and its furnace & A/C. 
** In pass-through operation it passes all thermostat control signals unchanged through to the furnace.
**
** It accepts commands over its RFM69 packet radio that it uses to set into modes
** that modify the 24VAC communication between furnace/air condition and its thermostat.
** And it sends reports over the RFM69.
**
** The PCB and sketch designs handle up to 6 wires of 24VAC control inputs (from
** the wall thermostat), and 7 control outputs (to the furnace & A/C). 
** The 6 inputs, for example, usually include W for heat, G for fan, Y for a compressor (either AC or heat pump)
** O or B for a reversing valve. A multi-stage furnace, heat pump, and/or air conditioners each might 
** add another wire.
**
** "Communicating" thermostats, i.e., that do not have 24V AC wiring to the furnace, are not supported.
**
** A Serial LCD display is supported via a qwiic connector. A calendar/clock (RTC) is also supported
** on qwiic. This board/sketch does not support any user input except via the packet radio and/or
** Arduino serial port. It has a micro-USB connector that is used to program the Arduino 
** and help with debugging, and to configure the EEPROM.
**
** The mapping between the generic signal names in this sketch/PCB (X1, X2, Z1, Z2, ZX) and typical 
** thermostat wire names (O, B, Y, Y2, G) does not appear in this sketch. The only exceptions are 
** these two wires:
**      The W wire is assumed to be the furnace wire and 
**      R is assumed to be the 24VAC supply from the furnace.
**
** W is special. It is the one wire that the PCB passes through to the furnce when this PCB is turned off.
** That is, the heat function on the furnace still works, but no compressor.
** There is nothing in the PCB nor sketch that demands that W be the standard furnace W function. W is simply
** the signal wire that passes through the PCB when its power is off.
**
** This sketch supports multiple HVAC "types" (see HVAC.cpp). The types are numbered starting at zero,
** and type zero is the trivial type named PassThrough. The PassThrough type copies each if the 6 input
** signals to its corresponding output.
** 
** The remaining types are documented in HVAC.cpp. Each of those types has settings in EEPROM that 
** determine the behavior of this sketch/PCB when set to that type.
*/

// libraries
#include <RFM69.h>
#include <Wire.h>
#include <SPI.h>
#include <EEPROM.h>
#include <SerLCD.h>
#include <SparkFun_RV8803.h>

// VERSION_STRING is the SKETCH version. Not the PCB version. This sketch supports all PCB versions
#define VERSION_STRING "Rev 06" 

// This sketch has been tested ONLY on Sparkfun Pro Micro 8MHz and Teensy 4.0

#if defined(ARDUINO_ARCH_AVR) // PCB versions up through 3 are Sparkfun Pro Micro
/*This sketch with all options won't fit the Pro Micro unless you "upload with programmer" and
** have no bootloader. https://forum.arduino.cc/t/removing-bootloader-atmega32u4/598120/2 */
#include <avr/wdt.h>
namespace {
    void WATCHDOG_DISABLE() {
        MCUSR &= ~(1 << WDRF); // https://github.com/baerwolf/USBaspLoader/issues/6
            wdt_disable(); }
    void WATCHDOG_ENABLE() {wdt_enable(WDTO_2S); }
    void WATCHDOG_FEED() {wdt_reset();}
}
#elif defined(TEENSYDUINO) // PCB version 4 is a Teensy 4.0
#include <Watchdog_t4.h> // https://github.com/tonton81/WDT_T4.git
namespace {
    WDT_T4<WDT1> wdt;
    void WATCHDOG_ENABLE()
    {   WDT_timings_t config;
        config.timeout = 2; /* in seconds, 0->128 */
        wdt.begin(config);
    }
    void WATCHDOG_FEED() {  wdt.feed();   }
    void WATCHDOG_DISABLE(){}
}
#endif

// custom library
#include <RadioConfiguration.h>
#include "Rfm69RawFrequency.h"
#include "ThermostatCommon.h"


#define ENABLE_OUTPUT_RELAYS 1  // for testing, the sketch can be built with outputs disabled.
#define SCHEDULE_ENTRIES 1 // set to zero to remove this feature
#define SERIAL_PORT_BAUDS 9600

static_assert(sizeof(decltype(1L)) >= 4, "L suffix must get at least 32 bits");

#if defined(F_CPU) && F_CPU > 200000000L
class RFM69delayCanSend : public RFM69rawFrequency
{
public:
    RFM69delayCanSend(int nss, int irq) : RFM69rawFrequency(nss, irq)
    {    }

    bool canSend() override
    {   /* this delay(1) is inspired by the  #ifdef ESP8266 in the library code
            https://github.com/LowPowerLab/RFM69        */
        auto ret = RFM69::canSend();
        if (!ret) delay(1);
        return ret;
    }
};
typedef RFM69delayCanSend ThermostatRFM69_t;
#else
typedef RFM69rawFrequency ThermostatRFM69_t;
#endif

namespace LCD {
    const byte MODE_COLUMN = 0;
    const byte MODE_ROW = 0;
    const byte TIME_COLUMN = 0;
    const byte TIME_ROW = 1;
    const byte HVAC_COLUMN=6;
    const byte HVAC_ROW = 0;
    const byte HVAC_TEMPERATURES_ROW = 1;
    const byte HVAC_TEMPERATURES_COLUMN = 6;
    const byte HVAC_COMPRESSORHOLD_ROW = 0;
    const byte HVAC_COMPRESSORHOLD_COLUMN = 15;

    const long WHEN_TO_REINIT_INTERVAL_MSEC = 60000L * 3; // 3 minutes
    const int BANNER_TIME_MSEC = 10000;
    const int BANNER_REPEAT_MSEC = 500;
   
    SerLCD lcd;
    decltype(millis()) whenToReinit;
    bool reinit;
    bool showingBanner;
    decltype(millis()) bannerStarted;
    decltype(millis()) bannerRepeatStarted;

    void backlightOK() { lcd.setBacklight(64, 64, 64);  }
    bool banner() { return showingBanner;}

    void setup()
    {
        lcd.begin(Wire);
        delay(100);
        backlightOK();
        delay(100);
        lcd.setContrast(5);
        delay(100);
        lcd.noCursor();
        lcd.noBlink();
        lcd.noAutoscroll();
        lcd.clear();
        whenToReinit = millis() + WHEN_TO_REINIT_INTERVAL_MSEC;
        showingBanner = false;
    }

    void printMode(const char *m)
    {
        if (banner()) return;
        lcd.setCursor(MODE_COLUMN, MODE_ROW);
        lcd.write(m);
        lcd.write(' ');
    }

    void printTime(const char *t)
    {
        if (banner()) return;
        lcd.setCursor(TIME_COLUMN, TIME_ROW);
        lcd.write(t);
    }

    void printTemperatures(const char *t)
    {
        if (banner()) return;
        lcd.setCursor(HVAC_TEMPERATURES_COLUMN, HVAC_TEMPERATURES_ROW);
        lcd.write(t);
    }

    void printOutputs(const char *p)
    {
        if (banner()) return;
        lcd.setCursor(HVAC_COLUMN, HVAC_ROW);
        lcd.write(p);
    }

    void printCompressorHold(const char *p)
    {
        if (banner()) return;
        lcd.setCursor(HVAC_COMPRESSORHOLD_COLUMN, HVAC_COMPRESSORHOLD_ROW);
        lcd.write(p);
    }

    enum {BACKLIGHT_UNKNOWN, BACKLIGHT_OFF, BACKLIGHT_ON} backlightShowMissing24V;
 
    void backLight(bool good)
    {   // change LCD backlight if R wire is not live.
        if (banner()) return;
        if (good) {
            if (backlightShowMissing24V != BACKLIGHT_ON)
            {
                backlightOK();
                lcd.clear();
                reinit = true;
            }
            backlightShowMissing24V = BACKLIGHT_ON;
        } else {
            if (backlightShowMissing24V != BACKLIGHT_OFF)
            {
                lcd.setBacklight(255, 0, 0);
                lcd.clear();
                reinit = true;
            }
            backlightShowMissing24V = BACKLIGHT_OFF;
        }
    }

    const char *prevBanner;
    void printBannerHold(const char *p)
    {
        lcd.clear();
        lcd.write(p);
        prevBanner = p; // don't like this, but the display, at startup, won't "hold" the text
        showingBanner = true;
        bannerStarted = bannerRepeatStarted = millis();
    }

    void loop(unsigned long now)
    {
        bool bOff = false;
        if (showingBanner)
        {
            if (TimerCompleted(now, bannerStarted, BANNER_TIME_MSEC))
            {
                showingBanner = false;
                bOff = true;
            }
            else if (TimerCompleted(now, bannerRepeatStarted, BANNER_REPEAT_MSEC))
            {
                bannerRepeatStarted = now;
                lcd.clear();
                lcd.write(prevBanner);
            }
        }
        if (bOff || (!showingBanner && TimerCompleted(now, whenToReinit, WHEN_TO_REINIT_INTERVAL_MSEC)))
        {
            whenToReinit = now;
            lcd.clear();
            reinit = true;
            backlightShowMissing24V = BACKLIGHT_UNKNOWN;
        }
    }
 }
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
void loop()
{   WATCHDOG_FEED();
    const auto now = millis();
    auto previousInputRegister = InputRegister;
    auto previousOutputRegister = OutputRegister;

    if (CompressorOffTimeActive && TimerCompleted(now, CompressorOffStartTime , 1000L * getCompressorHoldSeconds()))
    {   // deal with possible expiration of the compressor short cycle prevention timer
        CompressorOffTimeActive = false;
        Furnace::SetOutputBits();
#if USE_SERIAL >= SERIAL_PORT_VERBOSE
        Serial.println(F("Compressor off timer ended"));
#endif
    }

    if (HeatSafetyOffTimeActive && TimerCompleted(now,  HeatSafetyOffStartTime,  1000L * getHeatSafetyHoldSeconds()))
    {
        HeatSafetyOffTimeActive = false;
        Furnace::SetOutputBits();
#if USE_SERIAL >= SERIAL_PORT_VERBOSE
        Serial.println(F("Heat safety timer ended"));
#endif
    }

    if (!HeatSafetyOffTimeActive)
    {   // check inlet temperature in heat modes and shut down if EEPROM settings say so
        auto heatSafetySeconds = getHeatSafetyHoldSeconds();
        if (heatSafetySeconds > 0 && heatSafetySeconds != static_cast<uint16_t>(0xffff))
        {
            auto heatSafetyTempCx10 = getHeatSafetyTemperatureCx10();
            if (heatSafetyTempCx10 > 0)
            {
                if (heatSafetyTempCx10 <= TinletTemperatureCx10)
                {   // safety triggerred
                    for (uint8_t i = 0; i < NUM_HEAT_SAFETY_ENTRIES; i++)
                    {
                        HeatSafetyMask_t m = getHeatSafetyMask(i);
                        uint8_t bits = ~m.dontCareMask & Furnace::LastOutputWrite;
                        if (bits == m.mustMatchMask && m.toClear != 0)
                        { // table indicates this IS a heat mode, so shut down heat
                            HeatSafetyOffStartTime = millis();
                            HeatSafetyOffTimeActive = true;
                            LCD::printBannerHold(HeatSafetyBanner);
                            HeatSafetyShutoffMask = ~m.toClear;
                            Furnace::SetOutputBits();
#if USE_SERIAL >= SERIAL_PORT_VERBOSE
                            Serial.println(F("Heat safety timer triggered"));
#endif
                            break;
                        }
                    }
                }
            }
        }
    }

    {  // every second (or so) update the RTC time on the LCD
        const int LCD_TIME_UPDATE_MSEC = 1000;
        static msec_time_stamp_t lastLCDupdate = now - 1 - LCD_TIME_UPDATE_MSEC;
        if (TimerCompleted(now, lastLCDupdate, LCD_TIME_UPDATE_MSEC))
        {
            lastLCDupdate = now;
            rtc.updateTime();
            uint8_t hrs = rtc.getHours();
            uint8_t min = rtc.getMinutes();
            char *p = reportbuf;
            if (hrs < 10)
                *p++ = '0';
            else
            {
                *p++ = '0' + hrs / 10;
                hrs %= 10;
            }
            *p++ = '0' + hrs;
            *p++ = ':';
            if (min < 10)
                *p++ = '0';
            else
            {
                *p++ = '0' + min / 10;
                min %= 10;
            }
            *p++ = '0' + min;
            *p++ = 0;
            LCD::printTime(&reportbuf[0]);
            printHvacTemperatures();
            LCD::printCompressorHold(CompressorOffTimeActive ? "H" : " ");
        }
    }

    uint8_t inputsAsRead = 0;
    {   // read input signals. mask definitions correspond with those in OutputRegister
        uint8_t TempInputRegister = 0;
        if (digitalRead(PCB_INPUT_X1_PIN) == LOW)
            TempInputRegister |= 1 << BN_X1;
        if (digitalRead(PCB_INPUT_X2_PIN) == LOW)
            TempInputRegister |= 1 << BN_X2;
        if (digitalRead(PCB_INPUT_Z1_PIN) == LOW)
            TempInputRegister |= 1 << BN_Z1;
        if (digitalRead(PCB_INPUT_Z2_PIN) == LOW)
            TempInputRegister |= 1 << BN_Z2;
        if (digitalRead(PCB_INPUT_W_PIN) == LOW)
            TempInputRegister |= 1 << BN_W;
        if (digitalRead(PCB_INPUT_ZX_PIN) == LOW)
            TempInputRegister |= 1 << BN_ZX;
        if (digitalRead(PCB_INPUT_R_ACTIVE_PIN) == LOW)
            TempInputRegister |= 1 << BN_R;

        // deal with 60Hz AC to input signal conversion
        static msec_time_stamp_t LastSeenActive[NUMBER_OF_SIGNALS]; 
        static msec_time_stamp_t LastChecked; 
        static msec_time_stamp_t RestartedChecking; // some functions in loop() take longer than INPUT_AC_ACTIVE_MIN_MSEC
        // when restarting checking after missing that long, don't turn off outputs until we've seen enough inputs

        if (TimerCompleted(now, LastChecked,  INPUT_AC_ACTIVE_MIN_MSEC / 4))
            RestartedChecking = now;

        uint8_t mask = 1;
        for (uint8_t i = 0; i < NUMBER_OF_SIGNALS; i++, mask <<= 1)
        {
            if (TempInputRegister & mask)
            {
                LastSeenActive[i] = now;
                InputRegister |= mask;
            }
            else 
            {
                if (TimerCompleted(now, LastSeenActive[i],  INPUT_AC_ACTIVE_MIN_MSEC) &&
                    TimerCompleted(now, RestartedChecking,  INPUT_AC_ACTIVE_MIN_MSEC))
                    InputRegister &= ~mask;
            }
        }
        LCD::backLight(0 != (InputRegister & (1 << BN_R)));
        LastChecked = now;
        inputsAsRead = InputRegister;
        if (previousInputRegister != InputRegister || InputsToHvacFlag) // hvac can CHANGE inputregister
        {
            hvac->OnInputsChanged(InputRegister, previousInputRegister);
            Furnace::SetOutputBits();
        }
        InputsToHvacFlag = false;
    }

    {   // An ADC read takes a large number of cycles. Spread the 3 of them out through multiple loops
        static unsigned long lastTemperatureAcquireMsec;
        static enum {DO_T_INLET, DO_T_OUTLET, DO_OUTSIDE, DO_REPORT, WAIT_REPORT_INTERVAL} temperatureAcquireState;
        msec_time_diff_t diffMsec = now - lastTemperatureAcquireMsec;
        switch (temperatureAcquireState)
        {
        // the ADC reads are done on consecutive loop() calls
        case DO_T_INLET:
            if (diffMsec >= POLL_ADC_MSEC)
            {   // stay in D_T_INLETT for POLL_ADC_MSEC msec
                auto vTi = analogRead(T_LM235_INLET_PIN); // Pro Micro has 10bit A/D
                TinletADCsum += vTi;
                temperatureAcquireState = DO_T_OUTLET;
            }
            break;
        case DO_T_OUTLET:
            {
                auto vTi = analogRead(T_LM235_OUTLET_PIN); // Pro Micro has 10bit A/D
                ToutletADCsum += vTi;
                temperatureAcquireState = DO_OUTSIDE;
            }
            break;
        case DO_OUTSIDE:
                {
                auto vTi = analogRead(S1_7089U_OUTSIDE_PIN); // Pro Micro has 10bit A/D
                TexternalADCsum += vTi;
                numberReadsInSum += 1;
                if (numberReadsInSum >= NUMBER_TEMPERATURE_ADC_READS_TO_AVERAGE)
                    temperatureAcquireState = DO_REPORT;
                else
                    temperatureAcquireState = DO_T_INLET;
                lastTemperatureAcquireMsec = now;
            }
            break;
        case DO_REPORT:
            {
                radioTemperatureReport(TinletADCsum, ToutletADCsum, TexternalADCsum);
                TinletTemperatureCx10 = degreesCx10fromLM235ADCx64(TinletADCsum);
                lastTemperatureAcquireMsec = now;
                temperatureAcquireState  = WAIT_REPORT_INTERVAL;
            }
            break;
        case WAIT_REPORT_INTERVAL:
            if (diffMsec >= BETWEEN_REPORTING_TEMPERTURE_MSEC)
            {
                TexternalADCsum = 0;
                ToutletADCsum = 0;
                TinletADCsum = 0;
                numberReadsInSum = 0;
                lastTemperatureAcquireMsec = now;
                temperatureAcquireState = DO_T_INLET;
            }
            break;
        }
    }

    // check for Serial input
#if USE_SERIAL >= SERIAL_PORT_PROMPT_ONLY
    while (Serial.available())
    {
        auto c = Serial.read();
        if (c < 0)
            break;
        auto ch = static_cast<char>(c);
        bool isRet = ch == '\n' || ch == '\r';
        if (!isRet)
            cmdbuf[charsInBuf++] = ch;
        cmdbuf[charsInBuf] = 0;
        if (isRet || charsInBuf >= CMD_BUFLEN - 1)
        {
            routeCommand(cmdbuf, charsInBuf);
            Serial.println(F("ready>"));
            charsInBuf = 0;
        }
    }
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

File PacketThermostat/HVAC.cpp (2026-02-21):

/*

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
THE SOFTWARE IS PROVIDED "AS IS", WITHOUT WARRANTY OF ANY KIND, EXPRESS OR
IMPLIED, INCLUDING BUT NOT LIMITED TO THE WARRANTIES OF MERCHANTABILITY,
FITNESS FOR A PARTICULAR PURPOSE AND NONINFRINGEMENT. IN NO EVENT SHALL THE
AUTHORS OR COPYRIGHT HOLDERS BE LIABLE FOR ANY CLAIM, DAMAGES OR OTHER
LIABILITY, WHETHER IN AN ACTION OF CONTRACT, TORT OR OTHERWISE, ARISING FROM,
OUT OF OR IN CONNECTION WITH THE SOFTWARE OR THE USE OR OTHER DEALINGS IN
THE SOFTWARE.
*/

#include <Arduino.h>
#include <EEPROM.h>
#include "ThermostatCommon.h"

/* The various HVAC implementations are a mix of classes with subclasses, each itself being table-driven.
** There is a trivial class, PassThrough, and four (interesting) classes.
** Each of the four classes has runtime parameters that themselves are saved in EEPROM tables.
** 
** The command sequence for setting these tables up in EEPROM is:
**    (1) Set the number of EEPROM slots for the type of interest:
**              HVAC TYPE=n COUNT=m       where n goes from 1 through 4, and m is limited by EEPROM's 1024 byte size
**    (2) Set the current HVAC mode to one of the created slots:
**              HVAC TYPE=n MODE=m      where m must be less than what was set as COUNT=
**    (3) Fill in the parameters for the given TYPE. 
**          (a) HVAC NAME=xyz       for all types, including PASSTHROUGH
**          (b) HVACMAP=0x          for the MapInputToOutput (TYPE=1)
**          (c) HVAC_SETTINGS       for all the remaining classes (TYpe= 2, 3 and 4)
**          (d) HUM_SETTINGS              needed an addition for the COOL setting for the AUTO mode
*           (e) AUTO_SETTINGS       for AUTO
**    (4)   COMMIT command.         All the above set only the current memory and are lost on PCB power down. COMMIT 
**    puts the settings to EEPROM to survive power down.
**
** The sketch .ino file allows for the above commands to be sent either by Serial or by the packet radio.
*/

class HvacCommands; // base class                   
class PassThrough; // The trivial type is PassThrough

/* MapInputToOuput honors its thermostat inputs, but not unconditionally like PassThrough.
** Each combination of inputs is mapped through EEPROM settings to an output */
class MapInputToOutput;

/* OverrideAndDriveFromSensors ignores thermostat inputs and instead
** drives the furnace signals from what it sees in incoming radio packets.*/
class OverrideAndDriveFromSensors;
class HvacHeat; // subclass of OverrideAndDriveFromSensors
class HvacCool; // subclass of OverrideAndDriveFromSensors
class HvacAuto; // subclass of HvacCool -- switches between heat/cool

namespace
{   // support these types of mappings from available inputs to furnace outputs:
    enum HvacTypes { HVAC_PASSTHROUGH, HVAC_MAPINPUTTOOUTPUT, HVAC_HEAT, HVAC_COOL, 
#if HVAC_AUTO_CLASS
        HVAC_AUTO,
#endif
        NUMBER_OF_HVAC_TYPES };
    const int NUM_INPUT_SIGNAL_COMBINATIONS = 1 << NUM_HVAC_INPUT_SIGNALS;

    const int HVAC_EEPROM_TYPE_AND_MODE_ADDR = HVAC_EEPROM_START; // .ino source tells this C++ module where to start
    const int HVAC_SAVED_TYPE_AND_MODE_SIZE = 2; // the thermostat remembers it TYPE and MODE settings across power down. 2 bytes to save that

    const int HVAC_NUMBER_OF_MODES_IN_TYPE_ADDR = HVAC_EEPROM_TYPE_AND_MODE_ADDR + HVAC_SAVED_TYPE_AND_MODE_SIZE; 
    const int NUMBER_OF_HVAC_TYPES_IN_EEPROM = NUMBER_OF_HVAC_TYPES - 1; // PASSTHROUGH only has one MODE, so don't save it

    const int HVAC_MODES_EEPROM_START_ADDR = HVAC_NUMBER_OF_MODES_IN_TYPE_ADDR + NUMBER_OF_HVAC_TYPES_IN_EEPROM;
    
    extern HvacCommands* const ThermostatModeTypes[]; // forward declar

    uint8_t NumberOfModesInType(HvacTypes t)
    {   // The EEPROM settings for the various HVAC modes allow for a variable number of each type.
        if (t == HVAC_PASSTHROUGH)
            return 1; // exactly one PassThrough as it only has a NAME and no other parameters
        // one byte per type
        uint16_t addr = static_cast<int>(t) - 1;
        addr +=  HVAC_NUMBER_OF_MODES_IN_TYPE_ADDR;
        uint8_t ret = EEPROM.read(addr);
        if (ret == static_cast<uint8_t>(0xff))
            return 0;
        return ret;
    }

    void SetNumberOfModesInType(HvacTypes t, uint8_t count)
    {   // set in EEPROM
        if (t == HVAC_PASSTHROUGH)
            return; // cannot set PassThrough count
        uint16_t addr = static_cast<int>(t) - 1;
        addr +=  HVAC_NUMBER_OF_MODES_IN_TYPE_ADDR;
        EEPROM.write(addr, count);
    }

    uint16_t AddressOfModeTypeSettings(HvacTypes t, uint8_t which);
    const int NAME_LENGTH = 5; // without trailing null
}

const char HVAC_SETTINGS[] = "HVAC_SETTINGS ";
#if HVAC_AUTO_CLASS
const char AUTO_SETTINGS[] = "AUTO_SETTINGS"; // This is the AUTO heat setting only
#endif

/* These classes have a lot of member variables that are static.
** This is an optimization to keep memory usage down by taking
** advantage of the detail that only one of the instances is active at a time.
** The "static" attribute overlays much of the data in memory which,
** in C++ best practices, is generally a bad idea. Its like having global
** variables. */

class HvacCommands : public ThermostatCommon
{
public:
    struct Settings {
        char ModeName[NAME_LENGTH + 1]; // space for trailing null in memory, but not in EEPROM
    };
    void InitFromEeprom(uint8_t mode)
    {
        MyModeNumber = mode;
        ReadSettings();
    }
    virtual void TurnFurnaceOff() {  Furnace::UpdateOutputs(0); }
protected:
    // implement some of the pure virtuals from interface class
    bool ProcessCommand(const char* cmd, uint8_t len, uint8_t senderid, bool toMe) override;
    const char* ModeNameString() override {  return settingsFromEeprom.ModeName; }
    bool GetTargetAndActual(int16_t& targetCx10, int16_t& actualCx10) override { return false; }
    void loop(msec_time_stamp_t) override {}

     // add pure virtuals for subclasses
    virtual void CommitSettings() = 0; 
    virtual void ReadSettings() = 0;
    virtual void InitializeState() {}; // subclasses need not do this one

    uint16_t WriteEprom(uint16_t addr)
    {
 #if USE_SERIAL >= SERIAL_PORT_SETME_DEBUG_TO_SEE
        Serial.print(F("HvacCommands::WriteEprom a=0X"));
        Serial.println(addr, HEX);
#endif
        EEPROM.put(addr, settingsFromEeprom);
        auto ret = addr + sizeof(settingsFromEeprom);
#if USE_SERIAL >= SERIAL_PORT_VERBOSE
        int remaining = EEPROM.length();
        remaining -= ret;
        if (remaining < 0)
            Serial.println(F("ERROR: WriteEprom beyond capacity"));
        else
        {
            Serial.print(F("EEPROM remaining:"));
            Serial.println(remaining);
        }
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

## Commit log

2022-03-31 heat mode update
    [PCB.step]
2022-08-02 fix C7089 table lookup
    [PacketThermostat.ino]
2022-08-03 capacitor labels
2022-10-10 safety shutdown furnace on return air temperature setting
2022-10-29 maintain temperature setting on mode change
2022-10-31 report R wire
2022-11-03 support B wire as alternative to O
2022-11-30 fuse command
2022-12-17 w relay timer fix
    [PacketThermostat.ino]
2024-06-03 PasG mode and booster fan support
2024-09-30 aux fan
2026-02-06 extend HEAT times on stage 1 and stage 2 before going to stage 3
2026-02-16 3D printable model for Pro Micro programmer fixture
    [ProMicroISP.FCStd]
2026-02-21 PCB version 4 (Teensy 4.0) and Sketch version 6
    [1051330001.SLDPRT, 3091049.sldprt, 3091092.sldprt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]
2026-02-21 Revise PCB assembly notes and part availability
    Updated PCB assembly instructions and part links.
2026-02-24 Revise PCB description in README
    Updated description of PCB version and CPU in the photo.
2026-02-24 Clarify jumper instructions for furnace wiring
2026-04-30 PCB rev 05 cuz of obsolete notice for relay
